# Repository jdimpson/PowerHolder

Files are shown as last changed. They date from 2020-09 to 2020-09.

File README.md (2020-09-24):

# PowerHolder PCB

Another variation of the AdaFruit PowerBoost 1000C (https://www.adafruit.com/product/2465) adapted for Raspberry Pi Zero. This is functionally similar to the PowerBoard (https://github.com/jdimpson/PowerBoard), but this time, with a side car that holds an entire 18650 Lithium Ion cell. As with PowerBoard, adds a  schottkey diode and programmable tactile button and LED and patches the Low Battery (LBO) signal to the Pi via a level shifter.

Also significant, this board lets you choose whether you want to pick-and-place and then reflow your own electronic components, or just go out and buy a PowerBoost 1000C from AdaFruit. You still have to solder on a diode, the battery holder clips, and (if you want them) the signal LED, programmable button, enable switch, and the level shifting mosfet for the LBO signal. But most of the fiddly parts, notably the U1 and U2 controller chips, you can use from the standard AdaFruit product. Just solder the board into place in the matching header holes with the male header pins they provide, or get some female headers too (that option makes clearance problems).

Note: when you solder a Powerboost in place, it's JST socket won't be accessible. Presumably this is okay because the battery sidecar is right there. The drawback is that the sidecar assumes your 18650 cell has exposed electrical contact on each of the opposing ends of the cell cylinder, rather than wires or tabs spot-welded onto the battery then brought out to a JST or similar connector. You could cut off the connector and solder battery wires onto the BAT and GND pins of the header if you want, or to the plus and minus pads of the battery clips.

Other things worthy of note:
- The MicroUSB connector is not the same foot print as AdaFruit uses in their PowerBoost, because I couldn't figure out which part which part number it was. My chosen replacement still has the through-hole-ish studs for physical reinforcement like Adafruit uses, but the footprints are incompatible.
- A BOM export is provided, which contains Digi-Key part numbers as wellas vendor part numbers.
- Python software that works with the LBO signal, button, and LED are available in the [RPiIoT](https://github.com/jdimpson/RPiIoT) repo. You don't have to use this software to benefit from this board, but you do want to monitor GPIO26/Phy37 because when it goes low, the battery voltage has dropped near the point where the charge controller will soon switch off power.
- Auxillary header is provided for USB/5VDC electrical input if you don't want to use MicroUSB.
- Auxillary header is provided for boosted 5VDC electrical output if you want to power something else with this board (in addition to, or instead of, an RPi Zero). NOte this auxillary output is not protected by the schottkey diode. This is analogous to the USB output header that the original PowerBoost 1000C provides, although the sense resistors used to indicate availability of > 500 mA have been removed.
- Unlike most RPi Zero daughter boards (hats, although this does not qualify as a hat because it has no EEPROM and is larger than the starndard board footprint), this board makes more sense to mount _underneath_ the RPi Zero. You'd do this by soldering female headers into the bottom of the RPi Zero, or better yet, the stacking headers like this: https://www.adafruit.com/product/2223. THen put male headers on the PowerHolder, stack the Zero on the PowerHolder, and then put whatever you want on top of the Zero as normal. You can also put the PowerHolder on top of the Zero (with or without stacking header) but the battery placement make the whole thing look weird to me.
- The PowerBoost 1000C can source about 1 Amp of current. This is plenty for an RPi Zero, with enough to spare for a camera and another hat of some type. It might even be enough to power an RPi 1 plus or 2, and it will boot a 3 but you'll likely see warnings abou undercurrent conditions. It won't run a 3+ or a 4 (well, they say the 4 will adjust power usage, but I don't know if it adapts to as low as an amp, and I wouldn't want to waste a 4 in a low power configuration anyways). It also won't run a servo or other motor, because they seem to have such rapid current draw that the RPi Zero will reboot regularly, presumably due to voltage drop.

Changes 
- v1.01: Changed MicroUSB connector to one I can find on Digikey; move battery terminals further from RPi header; used thinner/narrower battery holder; add more plus and minus signs (near battery and the USB input header); improve location of component names; added circles around all used pins (squares around GND). 

TODO 
- Since the battery is now onboard, Figure out how to use NTC resistor ("THERM" in the schematic) to monitor battery temperature. This board provides a header to place the NTC, although I haven't experimented with it so have no recommendation for part to use.

Raspberry Pi Pins used:

- GPIO17/Phy11 is connected to a momentary / tactile switch. Available for arbitrary software control (typically running my powerboard.py and associated code from the [RPiIoT](https://github.com/jdimpson/RPiIoT) repo).
- GPIO27/Phy13 is connected to a resistor and then an LED. Available for arbitrary software control (e.g. flashing to show grace period, and typically running my powerboard.py and associated code from the [RPiIoT](https://github.com/jdimpson/RPiIoT) repo).
- GPIO26/Phy37 is connected to via transistor and appropriate hold up resistor to the LBO signal of the PowerBoost circuit. This is how the Raspberry Pi knows to shut down. The signal is held at battery level (but level shifted to 3.3 V before hitting the RPi) until the Li Ion battery level drops below 3.4VDC (or maybe it's 3.2V, I forget) at which point the LBO signal drops to ground. This tells the software on the RPi to do a graceful shutdown.
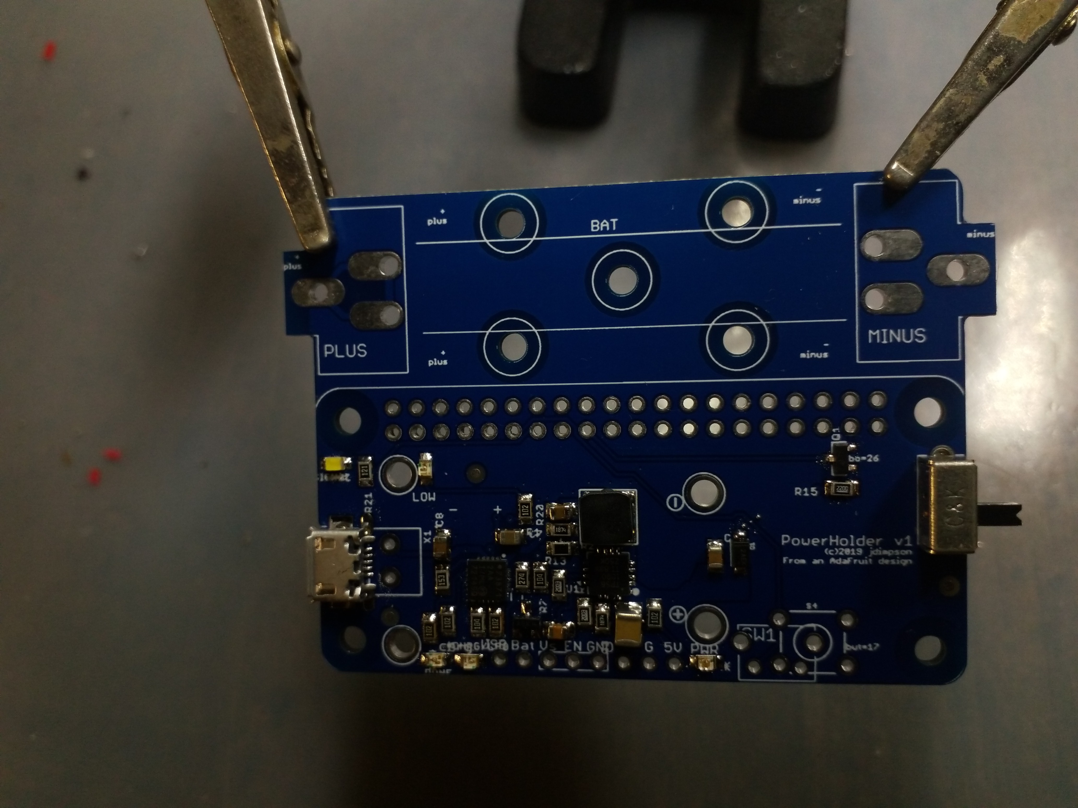
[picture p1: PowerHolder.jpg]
Image of board


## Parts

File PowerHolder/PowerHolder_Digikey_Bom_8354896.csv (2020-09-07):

Manufacturer Part Number | Manufacturer | Digi-Key Part Number | Customer Reference | Reference Designator | Packaging | Part Status | Quantity | Unit Price | Extended Price | Quantity Available | Mfg Std Lead Time | Description | RoHS Status | Lead Free Status | REACH Status
ERA-6AEB102V | Panasonic Electronic Components | P1.0KDACT-ND | R8,R14,R16,R20 |  | Cut Tape (CT) | Active | 5 | 0.33000 | $1.65 | 116316 | 13 Weeks | RES 1K OHM 0.1% 1/8W 0805 | ROHS3 Compliant | Lead free | REACH Unaffected
ERJ-6ENF1874V | Panasonic Electronic Components | P1.87BTCT-ND | R1,R3 |  | Cut Tape (CT) | Active | 2 | 0.10000 | $0.20 | 8428 | 11 Weeks | RES SMD 1.87M OHM 1% 1/8W 0805 | ROHS3 Compliant | Lead free | REACH Unaffected
ERA-6AEB104V | Panasonic Electronic Components | P100KDACT-ND | R7,R17 |  | Cut Tape (CT) | Active | 2 | 0.33000 | $0.66 | 113947 | 13 Weeks | RES 100K OHM 0.1% 1/8W 0805 | ROHS3 Compliant | Lead free | REACH Unaffected
ERA-6AEB153V | Panasonic Electronic Components | P15KDACT-ND | THERM |  | Cut Tape (CT) | Active | 1 | 0.33000 | $0.33 | 71459 | 13 Weeks | RES 15K OHM 0.1% 1/8W 0805 | ROHS3 Compliant | Lead free | REACH Unaffected
ERJ-PB6B2003V | Panasonic Electronic Components | P20854CT-ND | R4,R13 |  | Cut Tape (CT) | Active | 2 | 0.35000 | $0.70 | 121 | 13 Weeks | RES SMD 200K OHM 0.1% 1/4W 0805 | ROHS3 Compliant | Lead free | Not Available
ERA-6AEB274V | Panasonic Electronic Components | P270KDACT-ND | R6 |  | Cut Tape (CT) | Active | 1 | 0.33000 | $0.33 | 18848 | 13 Weeks | RES 270K OHM 0.1% 1/8W 0805 | ROHS3 Compliant | Lead free | REACH Unaffected
ERA-6AEB3403V | Panasonic Electronic Components | P340KDACT-ND | R2 |  | Cut Tape (CT) | Active | 1 | 0.33000 | $0.33 | 12228 | 13 Weeks | RES 340K OHM 0.1% 1/8W 0805 | ROHS3 Compliant | Lead free | REACH Unaffected
C1210C107M8PACTU | KEMET | 399-11631-1-ND | C6 |  | Cut Tape (CT) | Active | 1 | 1.58000 | $1.58 | 36692 | 8 Weeks | CAP CER 100UF 10V X5R 1210 | ROHS3 Compliant | Lead free | REACH Unaffected
C0805C225M8RACTU | KEMET | 399-9208-1-ND | C2 |  | Cut Tape (CT) | Active | 1 | 0.30000 | $0.30 | 14731 | 28 Weeks | CAP CER 2.2UF 10V X7R 0805 | ROHS3 Compliant | Lead free | REACH Unaffected
VLS5045EX-6R8M | TDK Corporation | 445-174855-1-ND | L1 |  | Cut Tape (CT) | Active | 1 | 0.45000 | $0.45 | 4874 | 12 Weeks | FIXED IND 6.8UH 2.9A 59.8 MOHM | ROHS3 Compliant | Lead free | REACH Unaffected
APHCM2012VBC/D | Kingbright | 754-2118-1-ND | PWR |  | Cut Tape (CT) | Discontinued at Digi-Key | 1 | 0.56000 | $0.56 | 1312 | Not Available | LED BLUE CLEAR 2SMD | ROHS3 Compliant | Lead free | REACH Unaffected
APHCM2012ZGCK-F01 | Kingbright | 754-2120-1-ND | DONE |  | Cut Tape (CT) | Active | 1 | 0.52000 | $0.52 | 0 | 12 Weeks | LED GREEN CLEAR 2SMD | ROHS3 Compliant | Lead free | REACH Unaffected
APT2012SECK | Kingbright | 754-1130-1-ND | CHRG/LBO |  | Cut Tape (CT) | Active | 1 | 0.41000 | $0.41 | 11845 | 12 Weeks | LED ORANGE CLEAR CHIP SMD | ROHS3 Compliant | Lead free | REACH Unaffected
APT2012EC | Kingbright | 754-1128-1-ND | LOW |  | Cut Tape (CT) | Active | 1 | 0.39000 | $0.39 | 32882 | 12 Weeks | LED RED CLEAR CHIP SMD | ROHS3 Compliant | Lead free | REACH Unaffected
S2B-PH-SM4-TB(LF)(SN) | JST Sales America Inc. | 455-1749-1-ND | B1 |  | Cut Tape (CT) | Active | 1 | 0.58000 | $0.58 | 0 | 16 Weeks | CONN HEADER SMD R/A 2POS 2MM | ROHS3 Compliant | Lead free | REACH Unaffected
MCP73871-2AAI/ML | Microchip Technology | MCP73871-2AAI/ML-ND | U2 |  | Tube | Active | 1 | 1.79000 | $1.79 | 2086 | 6 Weeks | IC USB/AC BATT CHRGR W/PPM 20QFN | ROHS3 Compliant | Lead free | REACH Unaffected
MMUN2133LT1G | ON Semiconductor | MMUN2133LT1GOSCT-ND | T1 |  | Cut Tape (CT) | Active | 1 | 0.12000 | $0.12 | 13716 | 4 Weeks | TRANS PREBIAS PNP 246MW SOT23-3 | ROHS3 Compliant | Lead free | REACH Unaffected
10118194-0001LF | Amphenol ICC (FCI) | 609-4618-1-ND | CN1 |  | Cut Tape (CT) | Active | 1 | 0.43000 | $0.43 | 26794 | 12 Weeks | CONN RCPT USB2.0 MICRO B SMD R/A | RoHS Compliant | Lead free | REACH Unaffected
TPS61090RSAR | Texas Instruments | 296-15259-1-ND | U1 |  | Cut Tape (CT) | Active | 1 | 2.34000 | $2.34 | 8334 | 6 Weeks | IC REG BOOST ADJUSTABLE 2A 16QFN | ROHS3 Compliant | Lead free | REACH Unaffected
ERA-6AEB121V | Panasonic Electronic Components | P120DACT-ND | R21 |  | Cut Tape (CT) | Active | 1 | 0.33000 | $0.33 | 19434 | 13 Weeks | RES 120 OHM 0.1% 1/8W 0805 | ROHS3 Compliant | Lead free | REACH Unaffected
ERJ-PB6B2200V | Panasonic Electronic Components | P20516CT-ND | R9 |  | Cut Tape (CT) | Active | 1 | 0.35000 | $0.35 | 9013 | 13 Weeks | RES SMD 220 OHM 0.1% 1/4W 0805 | ROHS3 Compliant | Lead free | Not Available
BSS138LT1G | ON Semiconductor | BSS138LT1GOSCT-ND | Q1 |  | Cut Tape (CT) | Active | 1 | 0.25000 | $0.25 | 944594 | 6 Weeks | MOSFET N-CH 50V 200MA SOT-23 | ROHS3 Compliant | Lead free | REACH Unaffected
ERJ-P06J512V | Panasonic Electronic Components | P5.1KADCT-ND | R5 |  | Cut Tape (CT) | Active | 1 | 0.11000 | $0.11 | 19640 | 13 Weeks | RES SMD 5.1K OHM 5% 1/2W 0805 | ROHS3 Compliant | Lead free | REACH Unaffected
CL21A106KPCLQNC | Samsung Electro-Mechanics | 1276-2402-1-ND | C1,C7,C8 |  | Cut Tape (CT) | Active | 3 | 0.14000 | $0.42 | 2656226 | 22 Weeks | CAP CER 10UF 10V X5R 0805 | ROHS3 Compliant | Lead free | REACH Unaffected
NRVTS245ESFT3G | ON Semiconductor | NRVTS245ESFT3GOSCT-ND | D1 |  | Cut Tape (CT) | Active | 1 | 0.33000 | $0.33 | 8249 | 10 Weeks | DIODE SCHOTTKY 45V 2A SOD123FL | ROHS3 Compliant | Lead free | REACH Unaffected
C0805C104K8RACTU | KEMET | 399-7999-1-ND | C4 |  | Cut Tape (CT) | Active | 1 | 0.20000 | $0.20 | 62964 | 8 Weeks | CAP CER 0.1UF 10V X7R 0805 | ROHS3 Compliant | Lead free | REACH Unaffected
IN-S85AT5UW | Inolux | 1830-1080-1-ND | SIGNAL |  | Cut Tape (CT) | Active | 1 | 0.43000 | $0.43 | 1348 | 5 Weeks | LED WHITE CLEAR 0805 SMD | ROHS3 Compliant | Lead free | Not Available
1825027-5 | TE Connectivity ALCOSWITCH Switches | 450-1662-ND | SW1 |  | Bulk | Active | 1 | 0.18000 | $0.18 | 51762 | 15 Weeks | SWITCH TACTILE SPST-NO 0.05A 24V | RoHS Compliant | Lead free | Not Available
OS102011MA1QN1 | C&K | CKN9559-ND | SW2 |  | Bulk | Active | 1 | 0.48000 | $0.48 | 61411 | 24 Weeks | SWITCH SLIDE SPDT 100MA 12V | ROHS3 Compliant | Lead free | REACH Unaffected
54 | Keystone Electronics | 36-54-ND | BAT |  | Bulk | Active | 2 | 0.63000 | $1.26 | 72370 | 6 Weeks | BATTERY CONTACT CLP 18650 PC PIN | ROHS3 Compliant | Lead free | REACH Unaffected

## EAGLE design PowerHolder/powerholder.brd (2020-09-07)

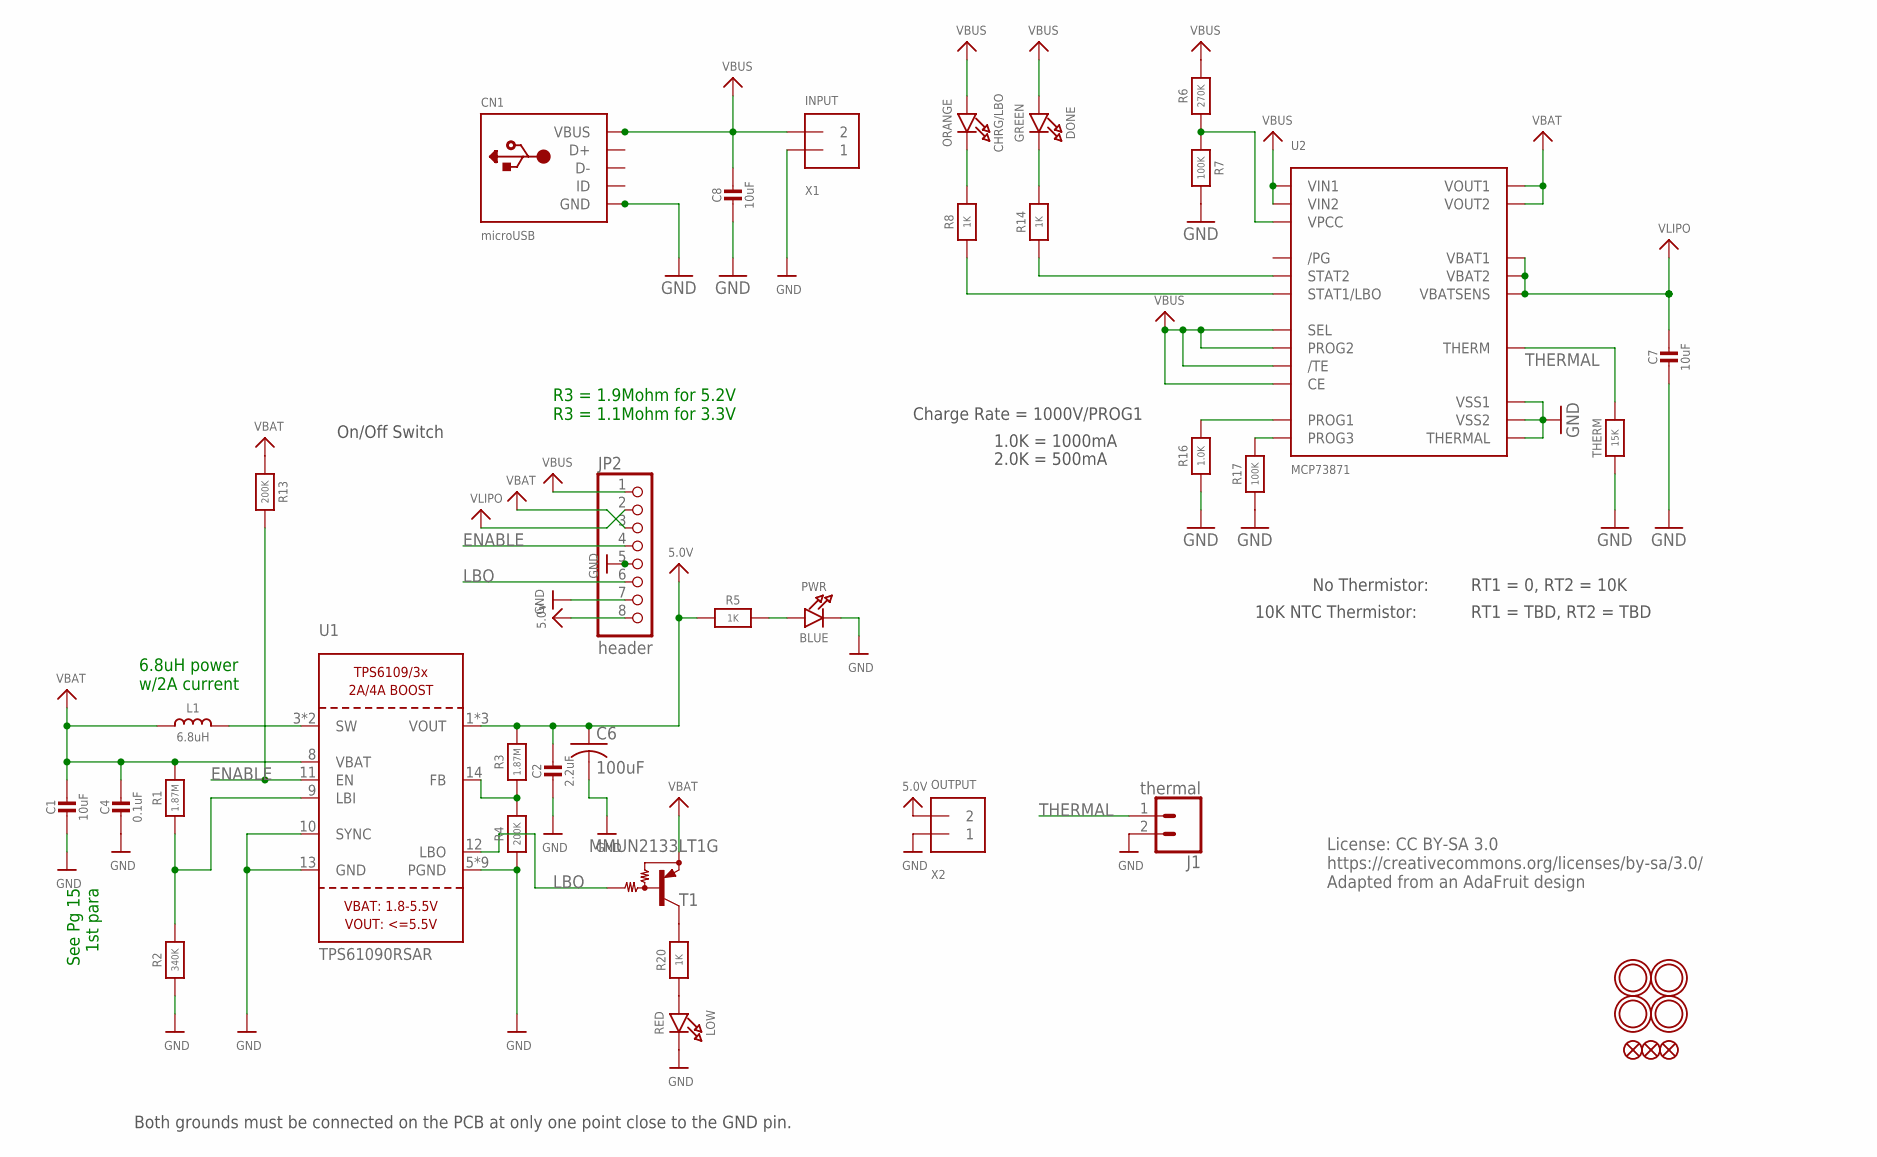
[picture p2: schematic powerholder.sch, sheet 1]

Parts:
C1, C7, C8: 10uF; 0805-NO@1
C2: 2.2uF; 0805-NO@1
C4: 0.1uF; 0805_10MGAP
C6: 100uF; C1210
CHRG/LBO: ORANGE; CHIPLED_0805_NOOUTLINE
CN1: microUSB; 4UCONN_20329
DONE: GREEN; CHIPLED_0805_NOOUTLINE
FID1, FID2, FID3: FIDUCIAL""; FIDUCIAL_1MM
J1: thermal; 1X02_NO_SILK
JP2: header; 1X08_ROUND
L1: 6.8uH; INDUCTOR_5X5MM_TDK_VLC5045
LOW: RED; CHIPLED_0805_NOOUTLINE
PWR: BLUE; CHIPLED_0805_NOOUTLINE
R1: 1.87M; _0805MP
R2: 340K; _0805MP
R3: 1.87M; 0805-NO
R4, R13: 200K; 0805-NO
R5, R8, R14, R20: 1K; 0805-NO
R6: 270K; 0805-NO
R7, R17: 100K; 0805-NO
R16: 1.0K; 0805-NO
T1: MMUN2133LT1G; SC59-BEC
THERM: 15K; 0805-NO
U1: TPS61090RSAR; PVQFN-16
U2: MCP73871; QFN20_4MM
U$10, U$11, U$50, U$51: MOUNTINGHOLE2.5; MOUNTINGHOLE_2.5_PLATED
X1: INPUT; TERMBLOCK_1X2-3.5MM
X2: OUTPUT; TERMBLOCK_1X2-3.5MM

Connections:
5.0V: C2.1, C6.1, JP2.8, R3.2, R5.1, U1.1 (VOUT), U1.15 (VOUT), U1.16 (VOUT), X2.2; also elsewhere on the board
ENABLE: JP2.4, R13.2, U1.11 (EN); also elsewhere on the board
GND: C1.2, C2.2, C4.2, C6.2, C7.2, C8.2, CN1.BASE@1 (GND), CN1.BASE@2 (GND), CN1.GND, CN1.SPRT@1 (GND), CN1.SPRT@2 (GND), CN1.SPRT@3 (GND), CN1.SPRT@4 (GND), J1.2, JP2.5, JP2.7, LOW.C, PWR.C, R2.1, R4.1, R7.2, R16.1, R17.1, THERM.1, U1.5 (PGND), U1.6 (PGND), U1.7 (PGND), U1.10 (SYNC), U1.13 (GND), U1.P$18 (PGND), U1.P$19 (PGND), U1.P$20 (PGND), U1.P$21 (PGND), U1.P$22 (PGND), U1.THERMAL (PGND), U2.P$10 (VSS1), U2.P$11 (VSS2), U2.P$21 (THERMAL), X1.1, X2.1; also elsewhere on the board
LBO: JP2.6, T1.B, U1.12 (LBO); also elsewhere on the board
unnamed: L1.P$2 (2), U1.3 (SW), U1.4 (SW)
unnamed: LOW.A, R20.1
unnamed: R1.1, R2.2, U1.9 (LBI)
unnamed: PWR.A, R5.2
unnamed: R3.1, R4.2, U1.14 (FB)
unnamed: R20.2, T1.C
unnamed: R6.1, R7.1, U2.P$2 (VPCC)
unnamed: DONE.C, R14.2
unnamed: R14.1, U2.P$7 (STAT2)
unnamed: R8.1, U2.P$8 (STAT1/LBO)
unnamed: CHRG/LBO.C, R8.2
unnamed: R17.2, U2.P$12 (PROG3)
unnamed: R16.2, U2.P$13 (PROG1)
THERMAL: J1.1, THERM.2, U2.P$5 (THERM)
VBAT: C1.1, C4.1, JP2.3, L1.P$1 (1), R1.2, R13.1, T1.E, U1.8 (VBAT), U2.P$1 (VOUT1), U2.P$20 (VOUT2); also elsewhere on the board
VBUS: C8.1, CHRG/LBO.A, CN1.VBUS, DONE.A, JP2.1, R6.2, U2.P$3 (SEL), U2.P$4 (PROG2), U2.P$9 (/TE), U2.P$17 (CE), U2.P$18 (VIN1), U2.P$19 (VIN2), X1.2
VLIPO: C7.1, JP2.2, U2.P$14 (VBAT1), U2.P$15 (VBAT2), U2.P$16 (VBATSENS); also elsewhere on the board

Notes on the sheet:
Both grounds must be connected on the PCB at only one point close to the GND pin.
On/Off Switch
See Pg 15 1st para
6.8uH power w/2A current
R3 = 1.9Mohm for 5.2V R3 = 1.1Mohm for 3.3V
Charge Rate = 1000V/PROG1
1.0K = 1000mA
2.0K = 500mA
No Thermistor:
10K NTC Thermistor:
RT1 = 0, RT2 = 10K
RT1 = TBD, RT2 = TBD
License: CC BY-SA 3.0 https://creativecommons.org/licenses/by-sa/3.0/ Adapted from an AdaFruit design

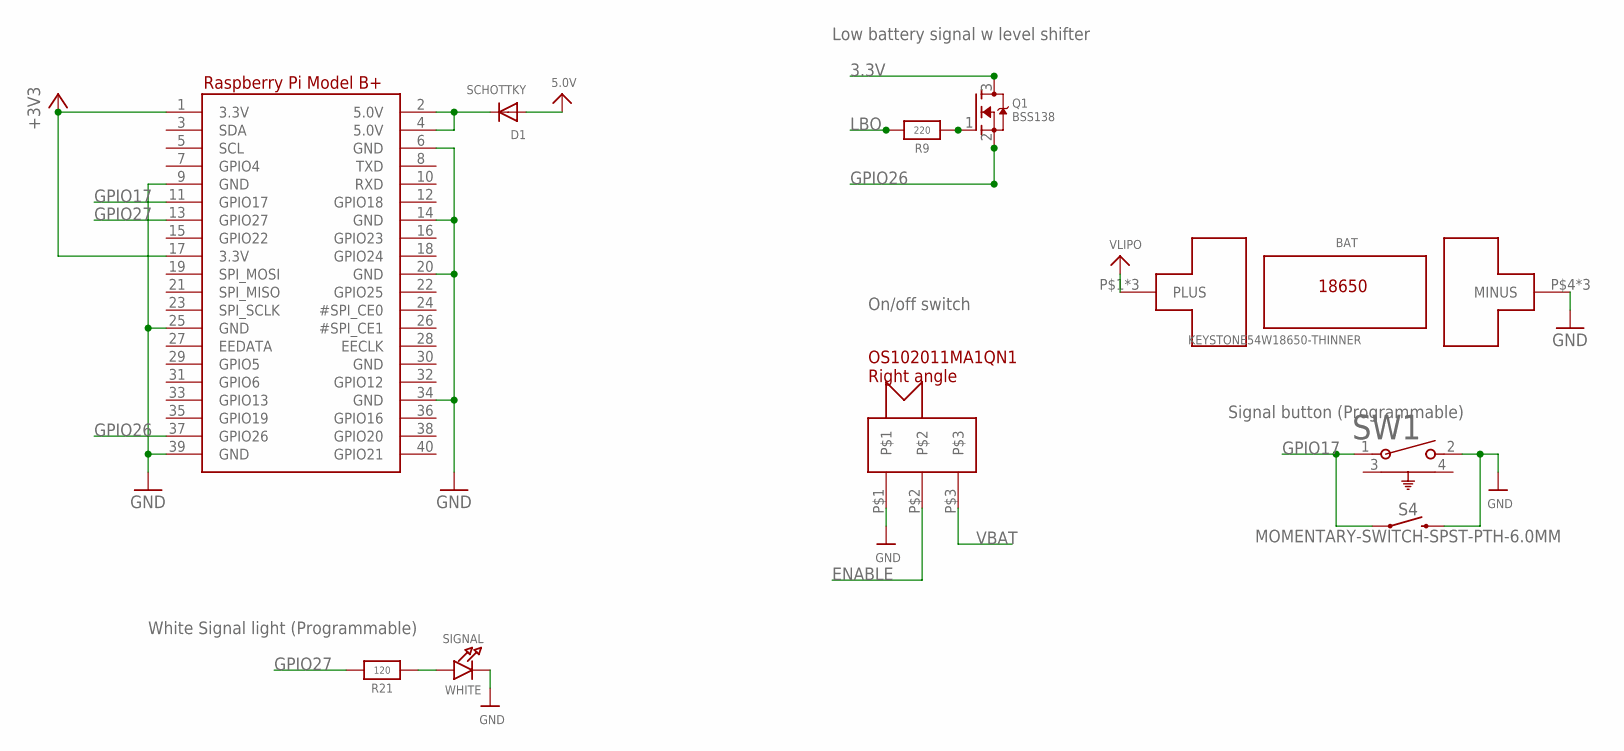
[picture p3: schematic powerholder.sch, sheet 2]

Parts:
BAT: KEYSTONE54W18650-THINNER
D1: SCHOTTKY; SOD-123FL
Q1: BSS138; SOT23-R
R9: 220; 0805-NO
R21: 120; 0805-NO
RPI1: RASPBERRYPI_BPLUS_BONNETNODIM; PI_BONNET_NODIM
S4: MOMENTARY-SWITCH-SPST-PTH-6.0MM; TACTILE_SWITCH_PTH_6.0MM
SIGNAL: WHITE; CHIPLED_0805_NOOUTLINE
SW1: 1825027-5; SW2_1825027-A
SW2: OS102011MA1QN1

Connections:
3.3V: Q1.3 (D), RPI1.1 (3.3V), RPI1.17 (3.3V)
5.0V: D1.A; also elsewhere on the board
5.0V@1: D1.C, RPI1.2 (5.0V), RPI1.4 (5.0V)
ENABLE: SW2.P$2; also elsewhere on the board
GND: BAT.P$4 (MINUS), BAT.P$5 (MINUS), BAT.P$6 (MINUS), RPI1.6 (GND), RPI1.9 (GND), RPI1.14 (GND), RPI1.20 (GND), RPI1.25 (GND), RPI1.30 (GND), RPI1.34 (GND), RPI1.39 (GND), S4.3 (2), SIGNAL.C, SW1.2, SW2.P$1; also elsewhere on the board
GPIO17: RPI1.11 (GPIO17), S4.1, SW1.1
GPIO26: Q1.2 (S), RPI1.37 (GPIO26)
GPIO27: R21.2, RPI1.13 (GPIO27)
LBO: R9.2; also elsewhere on the board
unnamed: Q1.1 (G), R9.1
unnamed: R21.1, SIGNAL.A
VBAT: SW2.P$3; also elsewhere on the board
VLIPO: BAT.P$1 (PLUS), BAT.P$2 (PLUS), BAT.P$3 (PLUS); also elsewhere on the board

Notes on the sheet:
Low battery signal w level shifter
On/off switch
Signal button (Programmable)
White Signal light (Programmable)

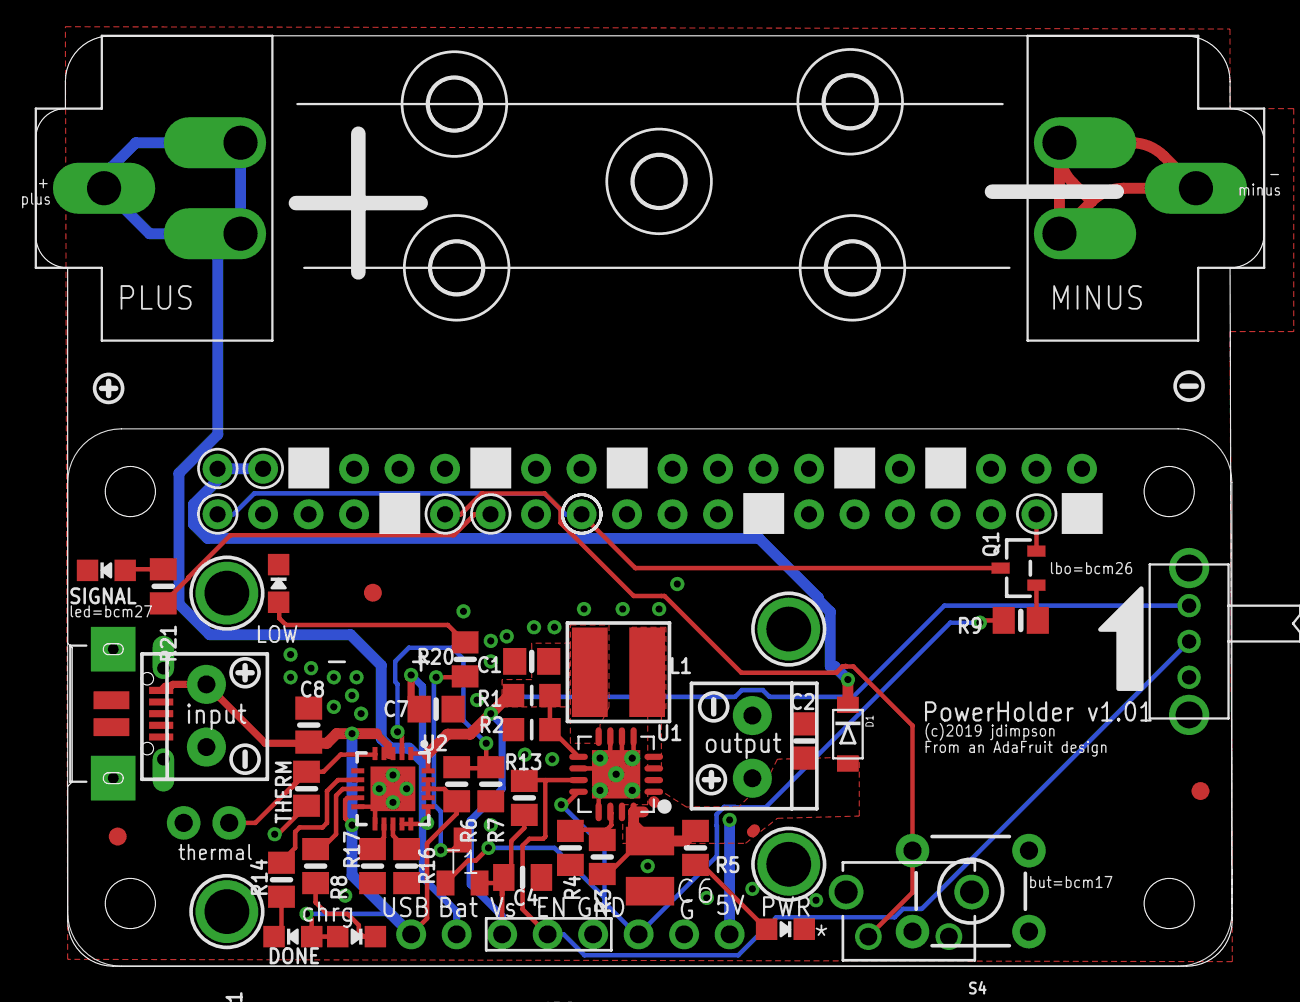
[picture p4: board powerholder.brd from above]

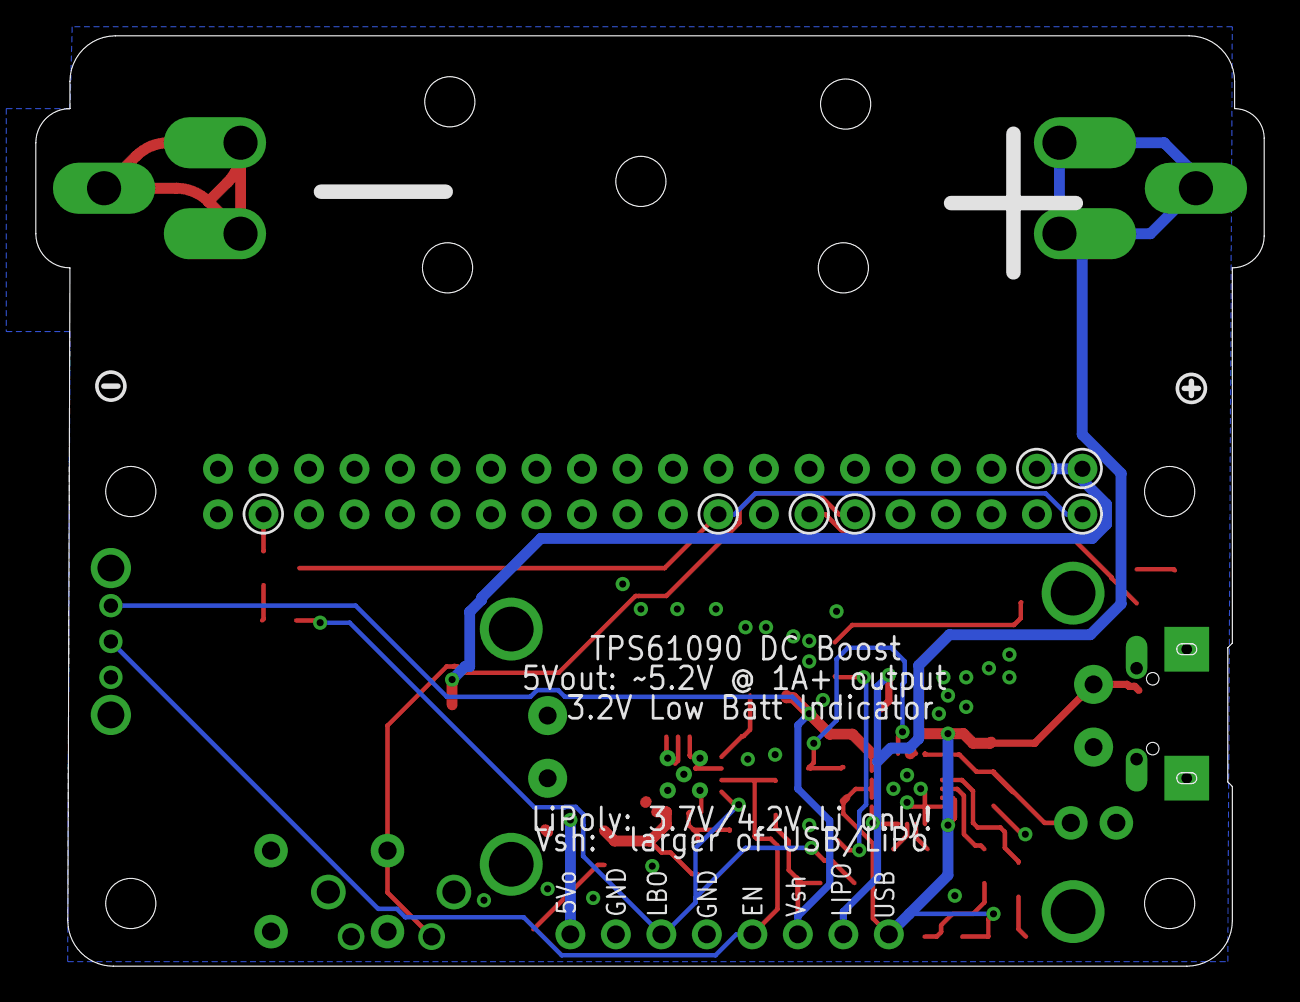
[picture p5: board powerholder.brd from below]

Board: 2 copper layers, 68.6 x 51.9 mm, 63 parts (2 on the bottom side), 28 nets.

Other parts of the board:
U$5, U$15, U$16, U$17, U$18: 2,8
U$12, U$28, U$53, U$54: SYMBOL_MINUS
U$21, U$22, U$45, U$52: SYMBOL_PLUS

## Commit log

2020-09-09 image of board
2020-09-24 Add that no JST socket is available
2020-09-24 Add pin description

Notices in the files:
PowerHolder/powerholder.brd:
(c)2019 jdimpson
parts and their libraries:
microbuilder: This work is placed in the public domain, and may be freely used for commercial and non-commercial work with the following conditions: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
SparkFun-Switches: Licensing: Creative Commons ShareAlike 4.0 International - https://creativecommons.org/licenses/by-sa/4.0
